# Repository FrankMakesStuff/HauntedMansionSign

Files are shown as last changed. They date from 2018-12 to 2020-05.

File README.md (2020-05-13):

# HauntedMansionSign
All the code and 3D files for my 3D-printed self-updating Haunted Mansion sign!

## About
The long-term goal of this project was to build a fan-made sign that would display the current wait-time of The Haunted Mansion, in Walt Disney World. I dunno, Disney fans have neat knick-knacks based on their fandom of the parks, so I had this idea of a little Haunted Mansion sign that would also show the current wait-time - my own personal little homage and link from my home to the park. Click the image below to watch it in action on YouTube:

(https://www.youtube.com/watch?v=Spqv1lANATA)

While I did not get that far, I was able to get the mechanics up and running, so here's the run-down of that. I salvaged a really cool motor from an old discarded printer. It had a rotary disc and optical encoder on the back of it, used for precise positioning, as is needed in desktop printers, scanners, etc. I ended up using interrupts to read the output from the encoder with an Arduino Nano, as the motor spun way too fast to get an accurate reading in the software main loop. As a consequence, I needed volatile access to the Arduino's memory within the interrupt to increment the counter value, which could cause the code to act funny -- this could probably be improved upon in later versions.

Lastly, I was able to expand the gear-train that came with the motor with my 3D printer, and I was able to use a really cool trick of swapping out filament colors during the print to get visible numbers (in white filament) on top of the (black) tooth-wheel. I had some fun figuring out the gear ratios and everything needed to call up any number on the wheel -- and that's basically where the project left off.

The rig could be controlled via serial access of the Arduino, but I expanded that a little using a Python script running Raspberry Pi that communicates serially to the Arduino - The idea being that, someday, if I ever do build this into my Haunted Mansion sign, it will simply sit on a shelf, the Pi communicates over the house Wi-Fi (using a really great library called [themeparks](https://github.com/cubehouse/themeparks) to get the actual real-time wait-time data from the parks, and update the motorized display, mimicking the real-life wait-time signs used at the theme parks.

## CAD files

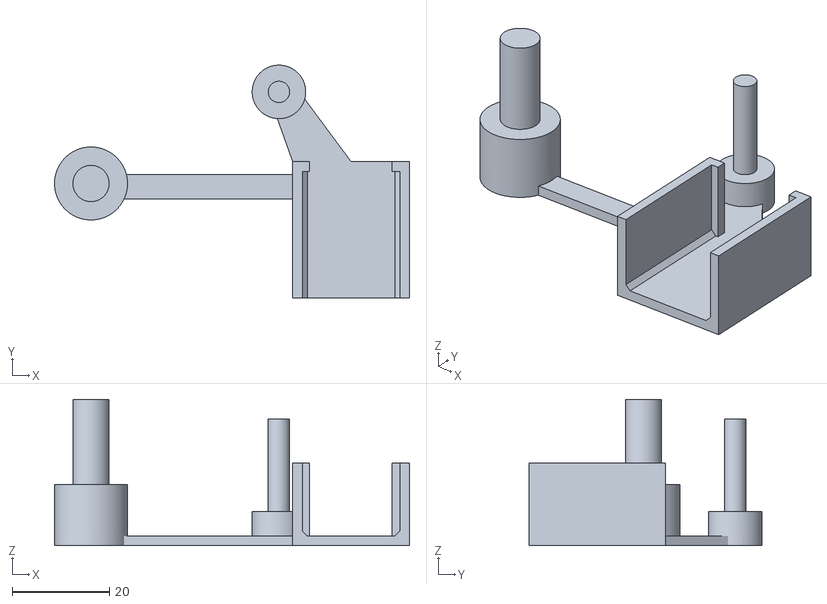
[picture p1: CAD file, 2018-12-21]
motor-mount.stl
72.9 x 47.8 x 30.0

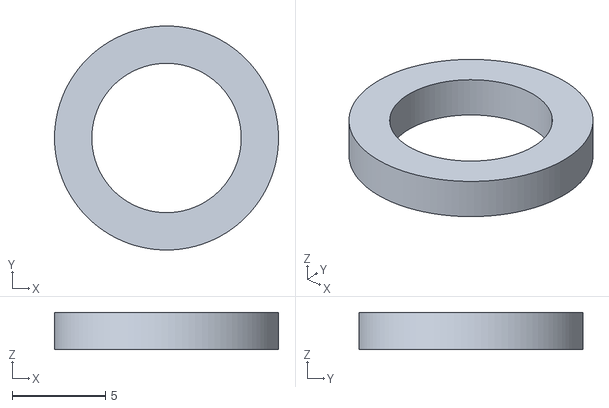
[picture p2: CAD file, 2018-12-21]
spacer.stl
12.0 x 12.0 x 2.00

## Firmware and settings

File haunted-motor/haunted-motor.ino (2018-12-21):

const byte PIN_MOTOR = 9;
const byte PIN_CH_A = 2;
const byte PIN_CH_B = 3;
const unsigned int ONE_REV = 2688;   // One revolution of the big wheel
const unsigned int ONE_TOOTH = 224;  // 32 stripes (64 on/off times) = one tooth of big wheel, 3.5 teeth of big wheel = 1 tooth of small wheel. 3.5 * 64 = 224
const unsigned long DIST = ONE_TOOTH;
const unsigned long SLOWDOWN = ONE_TOOTH * 2; // slow down when within 4 teeth of arrival

const byte MOTOR_SPEED = 255;
const byte MOTOR_SLOW = 120;

volatile byte stateA = LOW;
volatile byte stateB = LOW;
volatile byte lastA = LOW;
volatile byte lastB = LOW;

volatile long counter = 0;
long counter_copy = 0;
long countTotal = 0;
long offset = 0;

byte motorSpeed = 0;
bool isMotorRunning = false;

String serialInput = "";

void setup() {
  Serial.begin(9600);
  Serial.print("Motor power enabled. Beginning setup...\n");
  
  pinMode(PIN_MOTOR, OUTPUT);
  
  pinMode(PIN_CH_A, INPUT);
  pinMode(PIN_CH_B, INPUT);
  attachInterrupt(digitalPinToInterrupt(PIN_CH_A), interruptA, CHANGE);
  attachInterrupt(digitalPinToInterrupt(PIN_CH_B), interruptB, CHANGE);

  motorSpeed = 0;
  Serial.print("System ready! awaiting input...\n");
  analogWrite(PIN_MOTOR, motorSpeed);
  isMotorRunning=false;
}

void interruptA(){
  lastA = stateA;
  stateA = !stateA;
  getRotation();
}

void interruptB(){
  lastB = stateB;
  stateB = !stateB;
  getRotation();
}

void getRotation(){
  if( (stateA==HIGH) && (stateB==HIGH) ){
    if( lastA==LOW ){
      counter++;
    } else {
      counter--;
    }
  } else
  if( (stateA==LOW) && (stateB==LOW) ){
    if( lastA==HIGH ){
      counter++;
    } else {
      counter--;
    }
  }
}

void loop() {
    // if a variable is larger than a byte (long in this case) the data can become
    // corrupt if an interrupt happens to fire during a read/write. So, temporarily
    // disable them to get the value.
    noInterrupts();
    if( counter_copy < 0 ) counter = 0; // negative values indicate a reset is necessary
    counter_copy = counter;
    interrupts();

  // If motor is off, get Serial input
  if( !isMotorRunning ){
    if( Serial.available() > 0 ){
      int inChar = Serial.read();
      if( isDigit(inChar) ) serialInput += (char)inChar;
      
      // Once a 'newline' character is received:
      if( inChar == '\n' ){
        countTotal = serialInput.toInt();
        serialInput = "";
        Serial.print("Received: ");
        Serial.print(countTotal);
        Serial.print("\nSpinning...\n");

        countTotal *= ONE_TOOTH; // Multiply to get number of teeth needed from the big wheel to advance the little wheel by one tooth
        motorSpeed = MOTOR_SPEED; // full speed ahead!
        isMotorRunning = true;
      }
    }
  }

  // Motor runs as long as the counter is less than the designated value
  if( isMotorRunning ){

    // Set a slow-down if we're getting close to destination
    if( (counter_copy + SLOWDOWN) > countTotal ) // within slow-down range, apply slower motor speed for accuracy/reduced inertia
      motorSpeed = MOTOR_SLOW;

    // set motor PWM
    analogWrite(PIN_MOTOR, motorSpeed);

    // if we reach our desired rev count
    if( counter_copy >= (countTotal - offset )){
    
      // Stop the motor, delay to let all moving components settle to a complete stop
      digitalWrite(PIN_MOTOR, LOW);
      delay(800);

      // Get rotor overspin - this offset will be subtracted from the next motor operation
      noInterrupts();
      offset = counter - counter_copy;
      interrupts();

      Serial.print("Spinning complete!\n\nAwaiting input...\n");

      // Rotor has stopped, reset counter
      counter_copy = -1;

      // stop motor, wait for next Serial input
      motorSpeed = 0;
      analogWrite(PIN_MOTOR, motorSpeed);
      isMotorRunning = false;
    }
  }
}

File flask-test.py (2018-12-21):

from flask import Flask, request, render_template
import serial
import time

ser = serial.Serial()
ser.baudrate = 9600
ser.port = 'COM3'
ser.timeout=0

app = Flask(__name__)

@app.route('/')
def main():
	return render_template('main.html')

@app.route('/', methods=['POST'])
def my_form_post():
	text = ""
	getData = ""

	text = request.form['text']
	numRevs = int(text)
	print numRevs

	ser.open()
	while getData.find("input") < 0:
		getData = getData + ser.readline()
		print getData
		time.sleep(1)

	ser.write(str(numRevs) + '\n')

	time.sleep(1)

	ser.close()

	templateData = {
		'getData' : getData,
                'numRevs' : numRevs
	}

	return render_template('form.html', **templateData)

if __name__ == "__main__":
	app.run(debug=True, host='0.0.0.0', port=80)

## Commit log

2018-12-21 Upload from computer, included Arduino code/directory
2018-12-21 Added from computer - CLI upload
    [motor_mount.stl, spacer.stl]
2018-12-21 Looks like all accounted for...
    [motor_mount.stl, spacer.stl]
2018-12-21 renamed some files
    [motor-mount.stl]
2018-12-21 Added 2-part gcode files for number wheel (see readme)
